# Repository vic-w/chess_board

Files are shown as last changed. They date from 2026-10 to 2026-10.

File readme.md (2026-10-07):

用freecad画一个挂式的国际象棋棋盘。挂在墙上，设计要优雅有美感。
每一层格子下面都有一层小平台，用来摆放棋子。棋子还用到买来的立体磁性棋子。平台之间的空间要足够高，够摆下最高的棋子：国王。我的国王高度是50mm，直径20mm。
用黑白两种颜色组成。且不用ams，黑和白分开打印。
每一格要放下一个真实的立体棋子。每个格是一个长方形 28 * 56 mm。由于平台也要占用高度，所以整个棋盘也是一个比例大于2：1的长方形。
棋子放在每一层格子下面的平台上。平台宽度刚刚好能容纳棋子的直径。平台宽度可以刚好设置成20mm。磁铁在平台的中间位置。
平台的两条长的棱需要有倒角。
由于需要由拓竹A1 mini打印，打印不下整个棋盘，所以要分块来打印。
每块横向4格，纵向2格。共分8块。每块由黑色作为主框架，包含黑色的平台来摆放棋子。8个模块复用相同的图纸。要有挂钩位置，可以挂在墙上。块与块之间用蝴蝶形卡扣连接。
白色的方块单独打印，再嵌入到黑色框架中。框架本身就包含了黑色块，不需要单独打印黑色块。
平台上有64个直径4mm深度4mm的孔，可以嵌入磁铁。辅助固定棋子。
最后要给出美观的拼装手册
黑格和白格之间不要有隔断，平台要连续不要断开，也不需要有栏杆。
黑色框架要考虑打印的可行性，不能有薄片状结构。
需要一个"last move"标识牌，挂在平台上，要避开棋子的圆柱体。正面有last move字样。可以从上下卡住平台。
还需要一个在底部装棋子的小盒，利用蝴蝶卡扣挂在整个棋盘下面

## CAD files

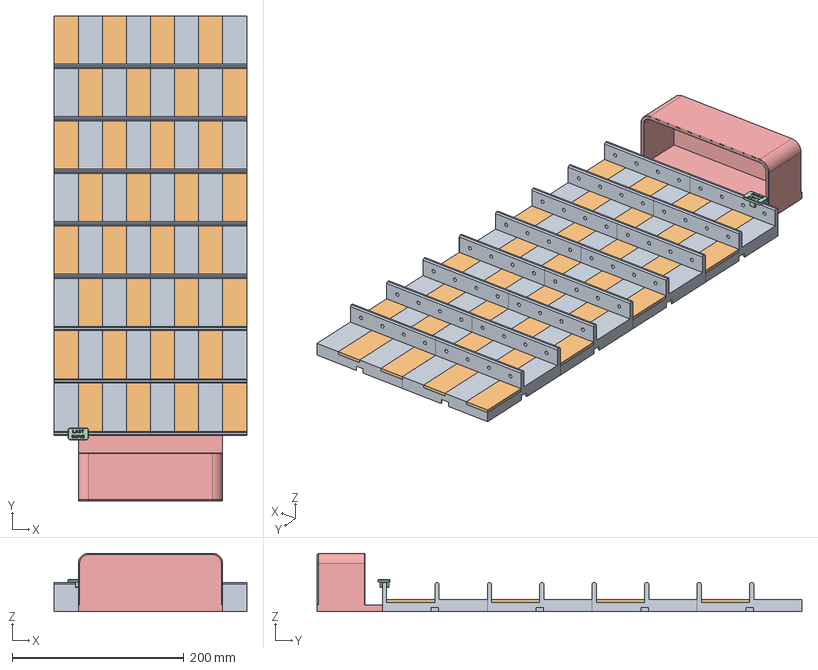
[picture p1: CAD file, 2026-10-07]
exports/wall_chess_board_assembly.step
224.0 x 564.0 x 68.0 mm

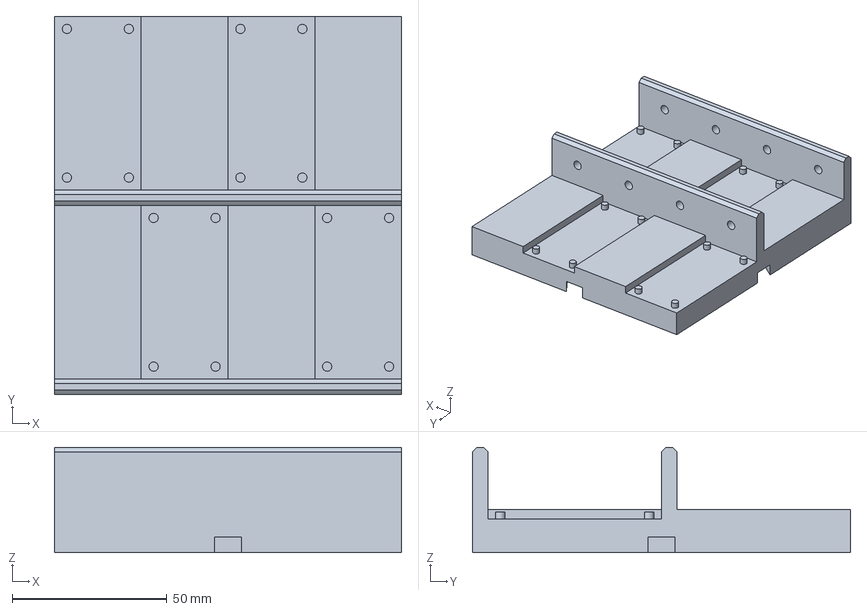
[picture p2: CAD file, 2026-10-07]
exports/black_module.step
112.0 x 122.0 x 34.0 mm

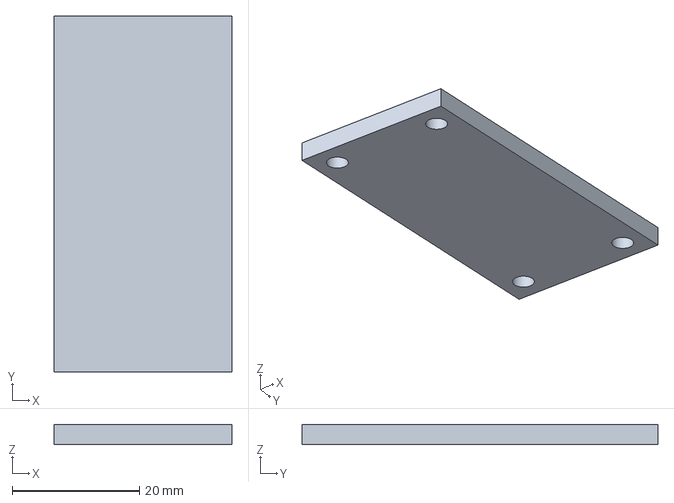
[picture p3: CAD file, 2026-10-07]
exports/white_tile.step
28.0 x 56.0 x 3.20 mm

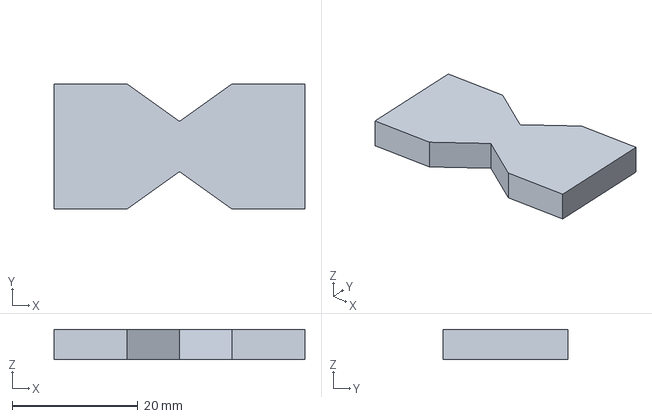
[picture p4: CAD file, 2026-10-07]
exports/butterfly_clip.step
40.0 x 20.0 x 4.80 mm

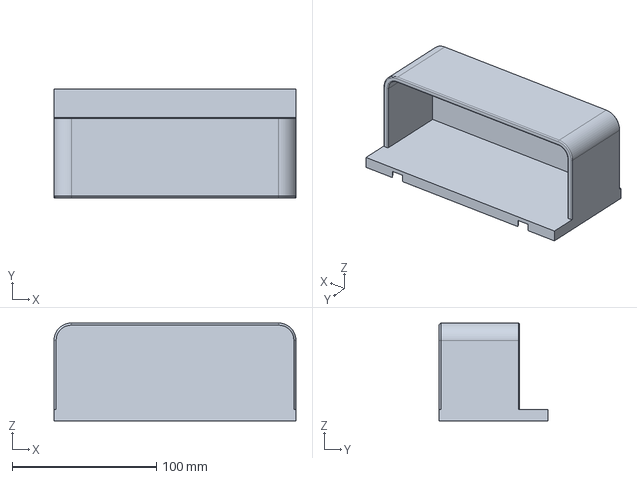
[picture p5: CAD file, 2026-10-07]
exports/storage_box.step
168.0 x 76.0 x 68.0 mm

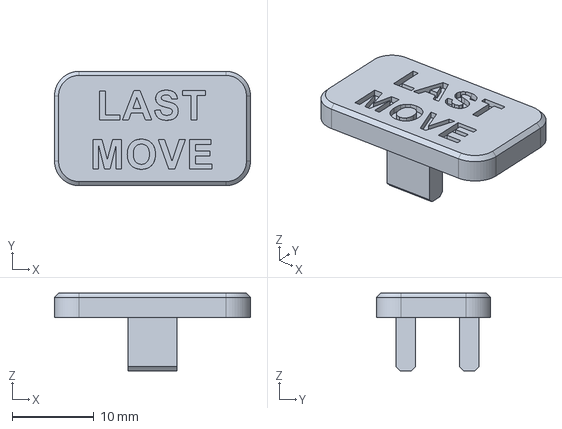
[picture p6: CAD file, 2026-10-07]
exports/last_move_marker.step
24.0 x 14.0 x 9.50 mm

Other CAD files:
WallChessBoard.FCStd
exports/black_module.stl
exports/butterfly_clip.stl
exports/last_move_marker.stl
exports/storage_box.stl
exports/white_tile.stl

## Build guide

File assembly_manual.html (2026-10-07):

WALL CHESS · A1 MINI EDITION

# 壁挂式国际象棋棋盘 拼装手册

八个相同的黑色模块组成 2×4 棋盘。每个棋格净尺寸为 28×56 mm；每层是一整条连续平台，黑白格之间没有隔条，平台前缘也没有栏杆。白色嵌块单独打印，嵌入黑色面板后与黑格齐平。

不需要 AMS黑白分开打印64 个磁铁孔

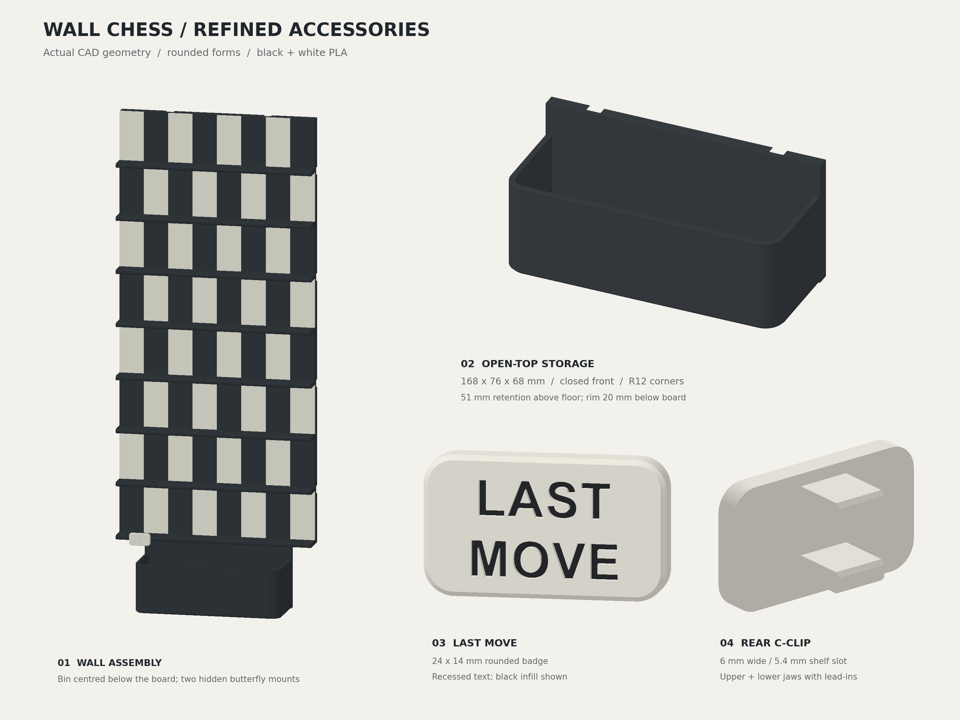
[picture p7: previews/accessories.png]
从交付 FreeCAD 实体生成的预览：整板、带完整前挡板的圆角收纳盒、LAST MOVE 字牌正面和背面的 C 形夹


实模预览 · 圆角、收口与文字均已建入实体。字牌凹字展示黑色填色效果，可打印后用细头油漆笔填色，无需 AMS。

01 / OPEN-TOP STORAGE

## 圆角收纳盒 · 上取式

完整前挡板连接两侧与盒底，挡板高 56 mm，内部有效挡高 51 mm。前角为 R12 圆弧，盒口做 R0.8 圆角，底边作 1.5 mm 倒角。

盒口低于棋盘底边 20 mm，向前伸出 68 mm；从前半部上方取放棋子。背板藏在棋盘下方，用两个蝴蝶卡扣连接。

168 × 76 × 68 mm（宽 × 总高 × 深）
侧壁 / 前挡板 4 mm · 底板 5 mm · 挂接背板 8 mm

下载收纳盒 STL · STEP

02 / LAST MOVE

## 白色字牌 · 窄幅 C 形夹

24 × 14 mm 圆角牌面，正面刻有 LAST / MOVE 两行字，字高约 3.7 mm、凹深 0.7 mm。R3 轮廓搭配 0.5 mm 正面倒角。

背后的夹子宽 6 mm，进入相邻棋子的间隙；上下夹爪形成 5.4 mm 槽，从前方套住 5 mm 平台。牌面位于平台前缘之外。

白色 PLA 单独打印 · STL 已将字面朝下
建议 0.16 mm 层高；先试装夹口，再按打印机实际公差微调。

下载标记 STL · STEP

## 成品与打印清单

8×黑色模块
112×122×34 mm

32×白色嵌块
28×56×3.2 mm

12×蝴蝶形卡扣
40×20×4.8 mm
模块 10 + 收纳盒 2

1×白色 LAST MOVE 字牌
24×14×9.5 mm（含 C 形夹）

1×圆角棋子收纳盒
168×76×68 mm

64×磁铁孔
Ø4 × 4 mm

2×4模块排列
整板 224×488 mm

文件：WallChessBoard.FCStd · exports/black_module.stl · exports/white_tile.stl · exports/butterfly_clip.stl · exports/last_move_marker.stl · exports/storage_box.stl · exports/storage_box.step · wall_chess_board_assembly.step

## 模块排列

## 安装顺序

打印黑色模块打印同一文件 8 份。模块平放，背面贴在打印平台；黑格和两层连续平台已包含在模块里。

打印白色嵌块打印白色小块 32 份。每块为完整白色单元尺寸，底面有 4 个定位盲孔。

压入磁铁每个格下的平台有 1 个 Ø4×4 mm 盲孔，共 64 个。磁铁顶部应与平台齐平或略低；先统一磁极方向。

嵌入白色小块把白块放入黑色框架的完整白格开口，底面贴住背板；四个盲孔分别套入黑色定位柱，表面与黑格齐平。

装入蝴蝶卡扣在相邻模块的边缘卡槽中插入 10 个蝴蝶形卡扣：竖向接缝 4 个，横向接缝 6 个。

打印与安装字牌使用白色 PLA，导出的 STL 已字面朝下；凹字可用黑色油漆笔填色。将 6 mm 夹子对准两个棋子的间隙，从平台前方套入，让上下夹爪夹住平台，字面朝外。

打印与挂接收纳盒STL 已按盒底朝下摆放，占地 168×68 mm，后部卡槽顶面可添加局部支撑。上墙前，将盒体居中放在整板下方，从背面在 x=56 / 168 mm 处压入两个卡扣。盒口朝上，前挡板朝外。

挂墙与调平先平放完成模块和收纳盒的背部卡扣装配，再挂墙调平。每个模块背面有左右两个钥匙孔挂点；挂点与墙体紧固件须共同承托装配件和棋子。

## 关键尺寸与余量

项目 | 尺寸
棋格净尺寸 | 28 × 56 mm
单格平台宽度 | 28 mm，整条 112 mm
平台伸出深度 | 20 mm
平台厚度 | 5 mm
平台长边倒角 | 两条，1.5 mm
棋王高度 / 直径 | 50 / 20 mm
可用净高 | 56 mm
行间距 | 61 mm（56 mm 净高 + 5 mm 平台带）
白色嵌块 | 28 × 56 × 3.2 mm
白格周边边墙 | 0 mm（完全取消）
定位柱 | 直径 3 mm、高 2.4 mm，每块白块 4 个
定位盲孔 | 直径 3.5 mm、深 2.65 mm
LAST MOVE 标识牌 | 24 × 14 × 9.5 mm，凹字 / 圆角 / C 形夹
标记夹口 | 宽 6 mm，槽高 5.4 mm，上下爪厚 2.4 mm
棋子收纳盒 | 168 × 76 × 68 mm，顶侧开口，前挡板高 56 mm
盒口与取放空间 | 盒口低于整板 20 mm，内挡高 51 mm
收纳盒挂接 | 2 个蝴蝶卡扣，挂在整板底边 x=56 / 168 mm
蝴蝶卡扣厚度 | 4.8 mm，已校核与现有背部卡槽无实体干涉
黑色后背板 | 14 mm；卡扣槽后约 9 mm

平台顶部到下一层平台下缘的净高为 56 mm，给 50 mm 高的棋王保留约 6 mm 余量。平台伸出 20 mm，磁铁孔位于平台深度中线，从平台上表面向下 4 mm，孔底保留 1 mm 材料。

## 墙面固定提示

钥匙孔位于模块背面，圆口直径 8 mm，窄槽宽 4.2 mm；螺钉头进入圆口后向上滑入背部宽槽，螺钉杆留在窄槽内。先用一块模块试装并确认螺钉头厚度与槽深匹配。墙体材质不同，螺钉和膨胀管请按实际墙体选用；每个模块建议使用左右两个挂点。

WallChessBoard · 参数化 FreeCAD 设计所有尺寸单位：mm
